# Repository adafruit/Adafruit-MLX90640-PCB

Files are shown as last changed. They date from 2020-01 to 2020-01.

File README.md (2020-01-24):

## Adafruit MLX90640 IR Thermal Camera Breakout PCB

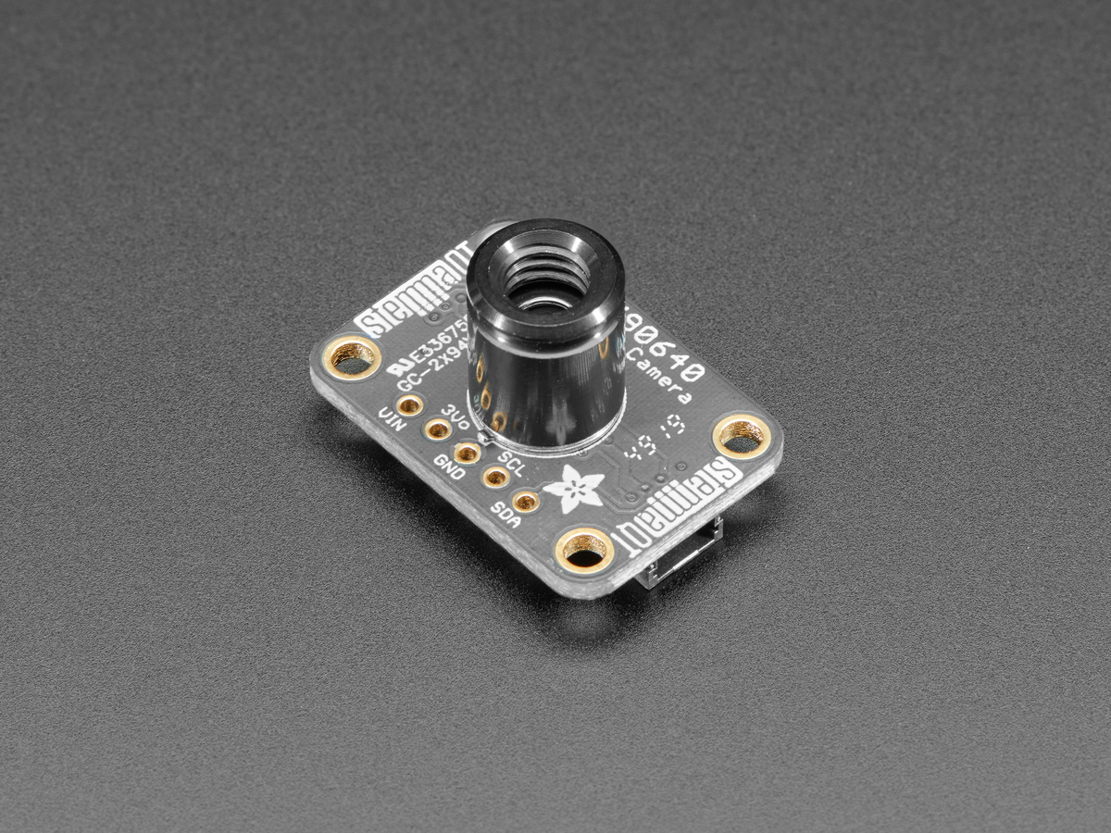
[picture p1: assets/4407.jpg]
<a href="http://www.adafruit.com/products/4407"><br/>
Click here to purchase one from the Adafruit shop</a><br/>
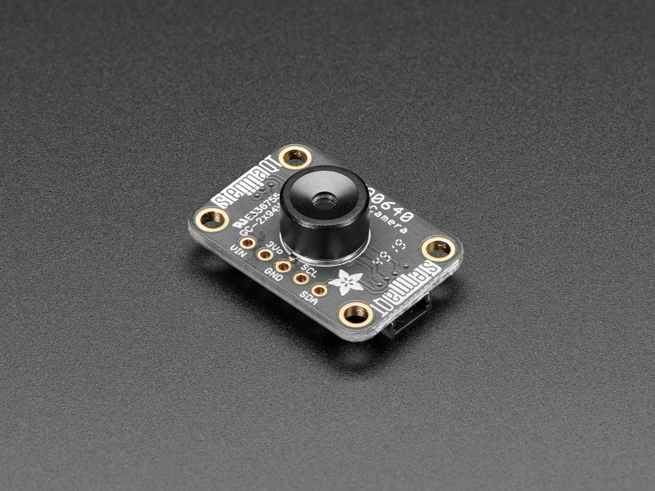
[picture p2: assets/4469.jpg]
<a href="http://www.adafruit.com/products/4469"><br/>
Click here to purchase one from the Adafruit shop</a>

PCB files for the Adafruit MLX90640 IR Thermal Camera Breakout. 

Format is EagleCAD schematic and board layout
* https://www.adafruit.com/product/4407
* https://www.adafruit.com/product/4469

### Description

You can now add affordable heat-vision to your project and with an Adafruit MLX90640 Thermal Camera Breakout. This sensor contains a 24x32 array of IR thermal sensors. When connected to your microcontroller (or Raspberry Pi) it will return an array of 768 individual infrared temperature readings over I2C. It's like those fancy thermal cameras, but compact and simple enough for easy integration.

One version has a narrow 55°x35° field of view, and we also have a version with a wider 110°x70° field of view

This part will measure temperatures ranging from -40°C to 300°C with an accuracy of +- 2°C (in the 0-100°C range). With a maximum frame rate of 16 Hz (the theoretical limit is 32Hz but we were not able to practically achieve it), It's perfect for creating your own human detector or mini thermal camera. We have code for using this sensor on an Arduino or compatible (the sensor communicates over I2C) or on a Raspberry Pi with Python. If using an Arduino-compatible, you'll need a processor with at least 20KB RAM - a SAMD21 (M0) or SAMD51 (M4) chipset will do nicely. On the Pi, you can even perform interpolation processing with help from the SciPy python library and get some pretty nice results!

This sensor reads the data twice per frame, in a checker-board pattern, so it's normal to see a checker-board dither effect when moving the sensor around - the effect isn't noticeable when things move slowly.

To make it easy to use, we hand-soldered it on a breakout board with a 3.3V regulator and level shifting. So you can use it with any 3V or 5V microcontroller or computer. We've even included SparkFun qwiic compatible STEMMA QT connectors for the I2C bus so you don't even need to solder! Just plug-n-play with any of our STEMMA QT (JST SH) cables.

Even better - We've done all the hard work here, with example code and supporting software libraries to get you up in running in just a few lines of Arduino or Python code

### License

Adafruit invests time and resources providing this open source design, please support Adafruit and open-source hardware by purchasing products from [Adafruit](https://www.adafruit.com)!

Designed by Limor Fried/Ladyada for Adafruit Industries.

Creative Commons Attribution/Share-Alike, all text above must be included in any redistribution. 
See license.txt for additional details.

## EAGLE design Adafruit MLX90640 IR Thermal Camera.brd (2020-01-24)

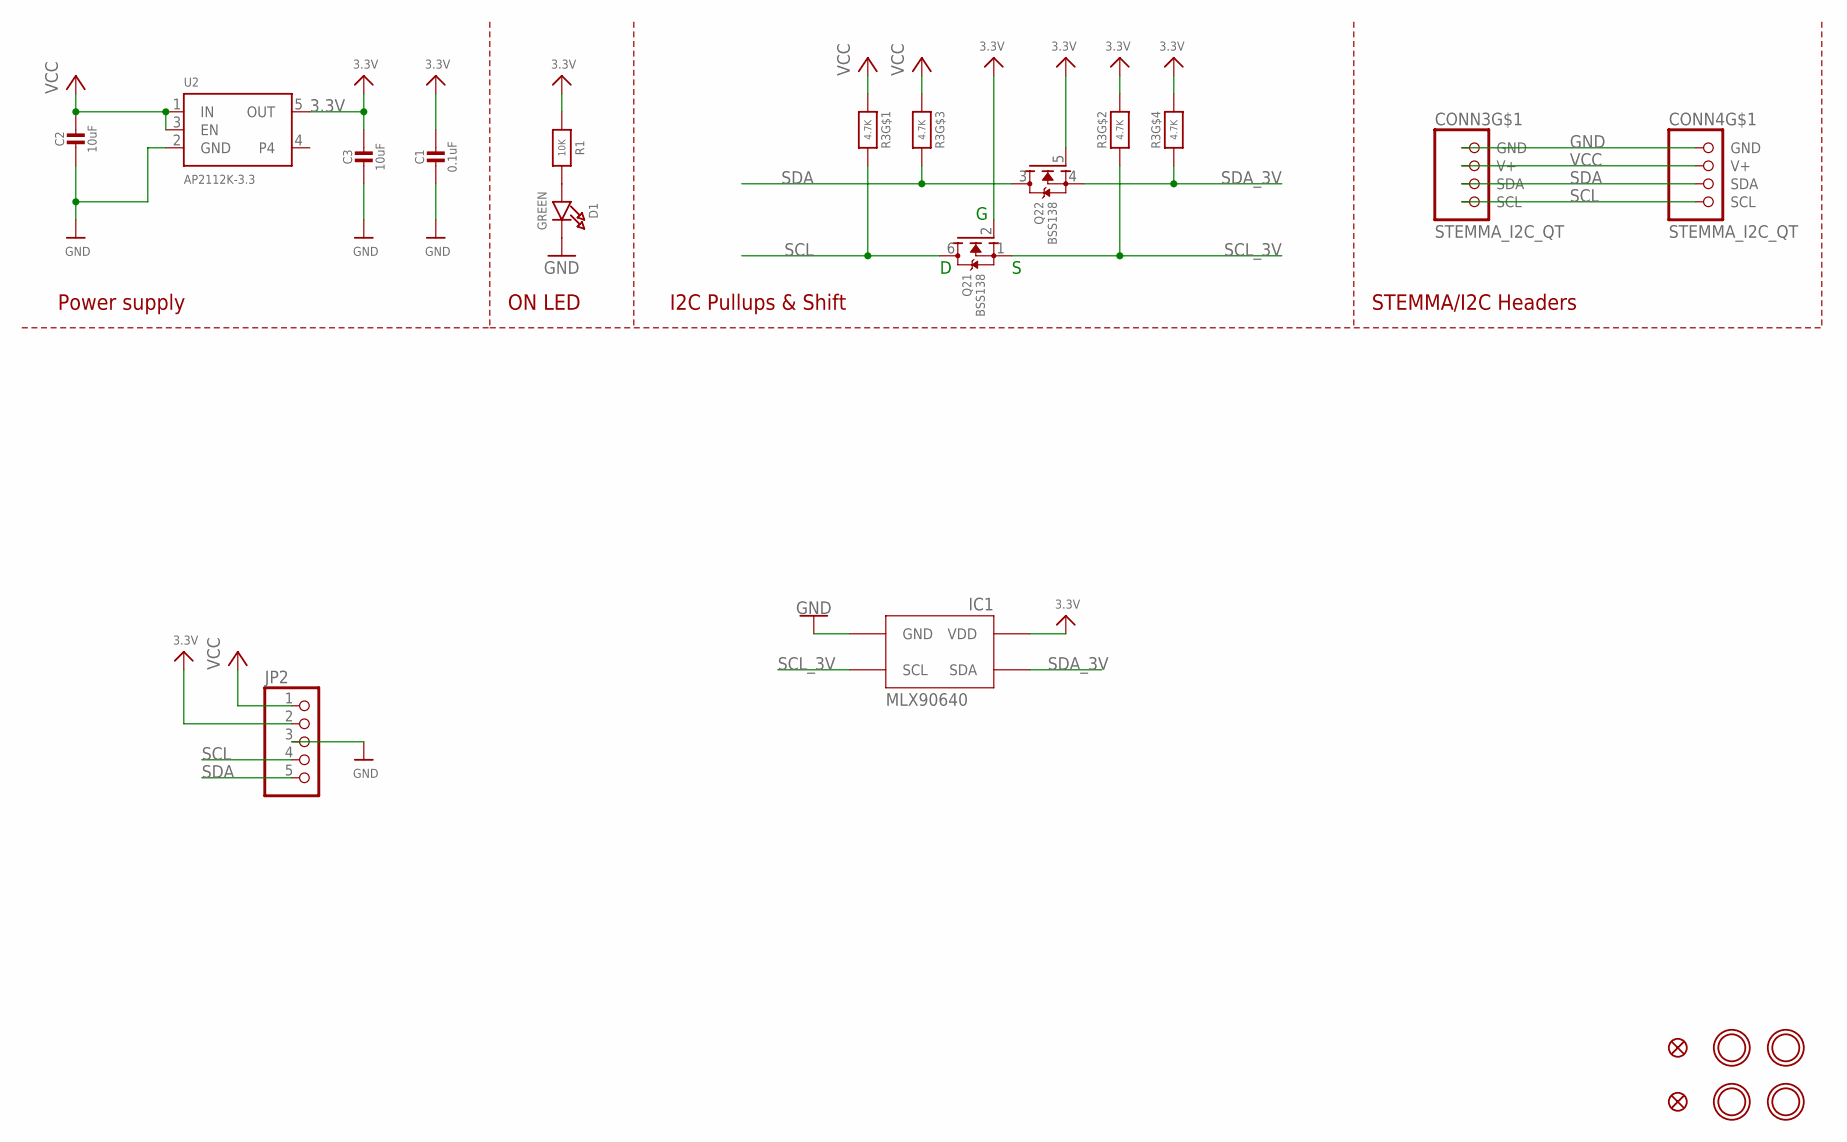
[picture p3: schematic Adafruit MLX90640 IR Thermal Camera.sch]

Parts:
C1: 0.1uF; 0603-NO
C2, C3: 10uF; 0805-NO
CONN3, CONN4: STEMMA_I2C_QT; JST_SH4
D1: GREEN; CHIPLED_0603_NOOUTLINE
FID3, FID4: FIDUCIAL_1MM
IC1: MLX90640
JP2: HEADER-1X5ROUND; 1X05_ROUND
Q2: BSS138; SOT363
R1: 10K; 0603-NO
R3: 4.7K; RESPACK_4X0603
U2: AP2112K-3.3; SOT23-5
U$1, U$17, U$19, U$21: MOUNTINGHOLE2.5; MOUNTINGHOLE_2.5_PLATED

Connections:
3.3V: C1.1, C3.1, IC1.VDD, JP2.2, Q2.2 (G), Q2.5 (G), R1.1, R3.2 (1), R3.4 (1), U2.5 (OUT)
GND: C1.2, C2.2, C3.2, CONN3.1 (GND), CONN4.1 (GND), D1.C, IC1.GND, JP2.3, U2.2 (GND)
unnamed: D1.A, R1.2
SCL: CONN3.4 (SCL), CONN4.4 (SCL), JP2.4, Q2.6 (D), R3.8 (2)
SCL_3V: IC1.SCL, Q2.1 (S), R3.7 (2)
SDA: CONN3.3 (SDA), CONN4.3 (SDA), JP2.5, Q2.3 (D), R3.6 (2)
SDA_3V: IC1.SDA, Q2.4 (S), R3.5 (2)
VCC: C2.1, CONN3.2 (V+), CONN4.2 (V+), JP2.1, R3.1, R3.3 (1), U2.1 (IN), U2.3 (EN)

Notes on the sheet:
I2C Pullups & Shift
STEMMA/I2C Headers
ON LED
Power supply

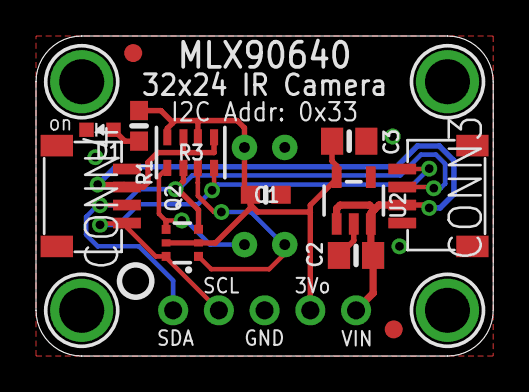
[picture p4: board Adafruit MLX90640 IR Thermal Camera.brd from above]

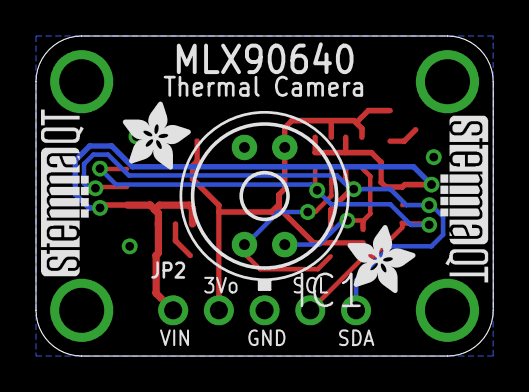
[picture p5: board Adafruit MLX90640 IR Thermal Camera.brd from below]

Board: 2 copper layers, 25.4 x 17.8 mm, 23 parts (6 on the bottom side), 8 nets.

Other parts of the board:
U$4, U$22: ADAFRUIT_3.5MM
U$25: PCBFEAT-REV-040
U$30, U$31: STEMMAQT

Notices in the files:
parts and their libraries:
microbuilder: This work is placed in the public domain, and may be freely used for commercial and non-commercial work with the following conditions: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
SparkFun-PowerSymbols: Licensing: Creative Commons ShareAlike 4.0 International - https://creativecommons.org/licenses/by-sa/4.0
